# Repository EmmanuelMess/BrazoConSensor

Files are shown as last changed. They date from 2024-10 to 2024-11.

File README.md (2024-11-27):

# Brazo con sensor

Es un brazo con un sensor laser de distancia. Permite tomar y soltar cosas desde una repisa.

## Demostración

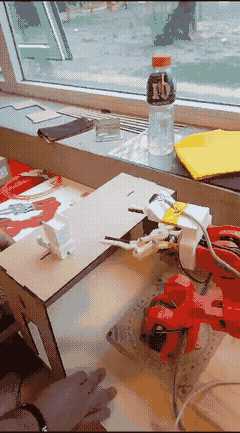
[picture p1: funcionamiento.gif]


## Partes

* 2 Arduino Mega: uno controla el brazo, y otro se comunica con el sensor.
* 2 Fuentes 5V: para los Arduinos.
* 1 Sensor VL6180x: mide la distancia entre el brazo y el objetivo.
* 1 Agarre para sensor: ver "AgarreBrazo.stl"
* 1 Brazo Braccio con agarre gripper
* 1 Repisa: donde el robot toma el objeto

## Instrucciones

1. Imprimir el modelo "AgarreBrazo.stl".
2. Instalar "SensorDetect/SensorDetect.ino" en el arduino del laser (puede requerir instalar dependencias).
3. Instalar "CinematicaInversa/CinematicaInversa.ino" en el arduino Mega del brazo (puede requerir instalar dependencias).
4. Conectar como se explica en el diagrama mas abajo
5. Instalar el agarre al brazo y asegurar que mida correctamente (Ver "Calibrar el sensor")

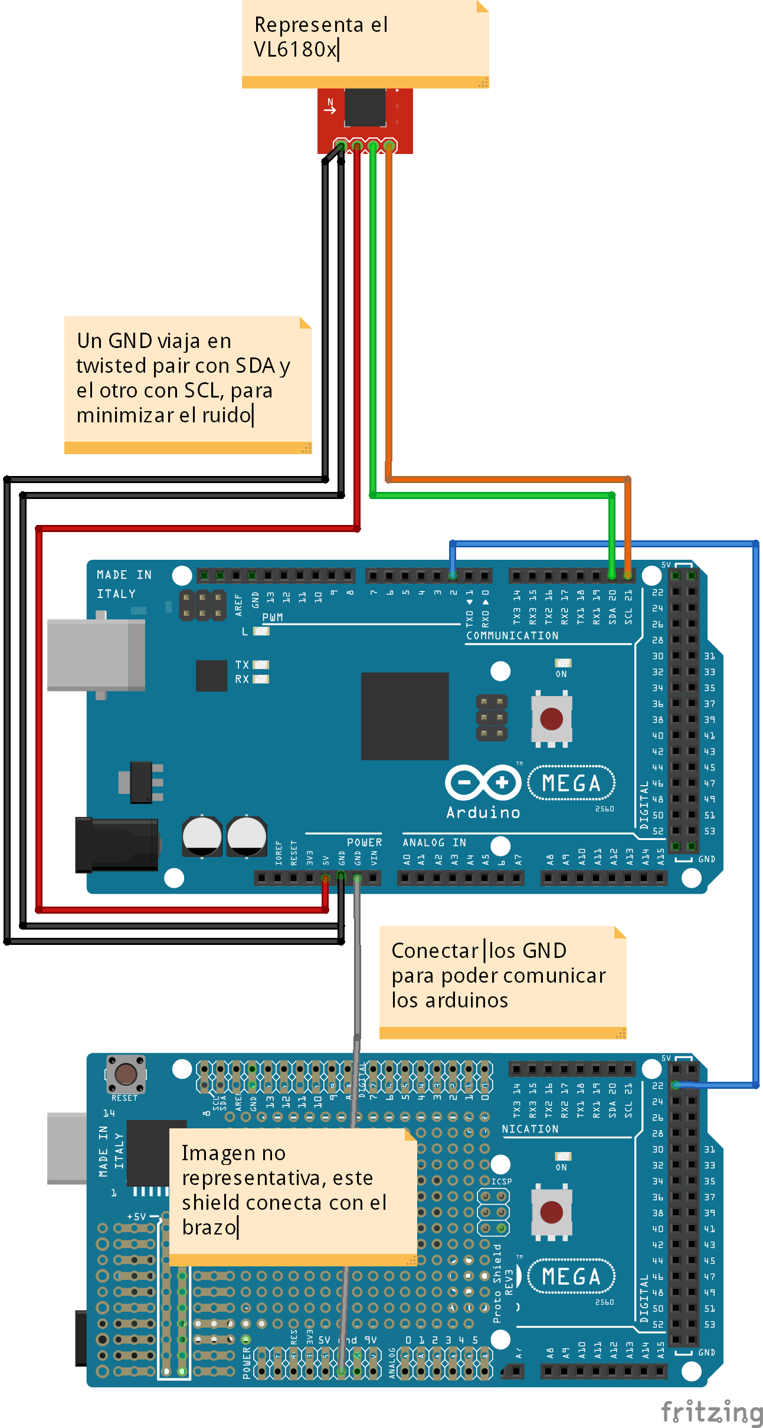
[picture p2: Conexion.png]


### Calibrar el sensor

Alimentar solo el sensor luego de haberlo colocado en el brazo. La salida de consola serial indica 
rangos sensados o errores. Validar que en el rango correcto, el sensor sense correctamente.

## Notas

### Uso de un ultrasonido

El sensor ultrasonido tiene dos problemas: el angulo de deteccion es muy granade y los falsos positivos son muy altos.
El angulo de deteccion del ultrasonido abarca más que el angulo que puede agarrar el brazo, generando choques entre la
mano y el objeto.  Otro problema es que es muy comun una deteccion cuando no hay ningun objeto. Ambos problemas se 
solucionan con un sensor de distancia laser.

### Uso de dos placas

Por cuestiones de mala calidad de los Arduinos, es critico usar dos placas independientes, comunicadas por un pin. Caso contrario,
el movimiento del brazo genera ruido impredecible en la lectura del sensor, generado errores y falsos negativos.

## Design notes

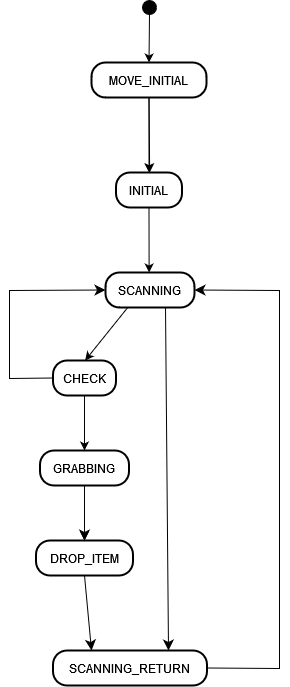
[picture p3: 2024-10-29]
DiagramaDeFlujoBrazo.png

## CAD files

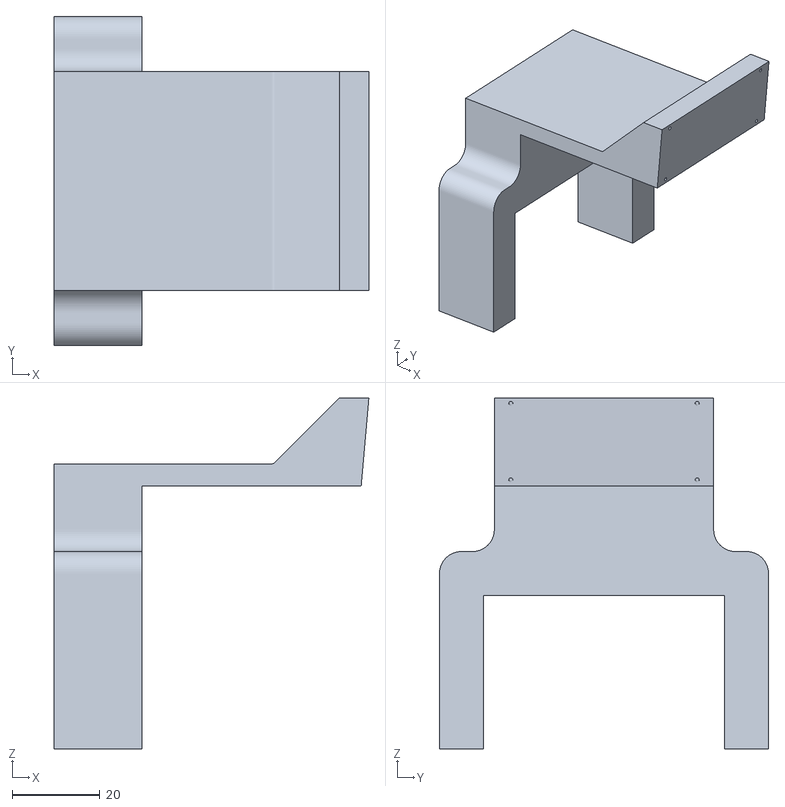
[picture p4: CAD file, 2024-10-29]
AgarreBrazo.stl
71.7 x 75.0 x 80.0

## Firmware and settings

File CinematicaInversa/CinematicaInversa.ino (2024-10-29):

#include <Braccio.h>
#include <Servo.h>

// Include the library InverseK.h
#include <InverseK.h>


const int sensorPin = 22;

Servo base;
Servo shoulder;
Servo elbow;
Servo wrist_rot;
Servo wrist_ver;
Servo gripper;

enum Action {
  INITIAL =  0,
  MOVE_INITIAL,
  GRABBING,
  SCANNING,
  SCANNING_RETURN,
  CHECK,
  DROP_ITEM
};

struct State {
  Action action;
  int x;
  int y;
  int z;
};

State state = { .action = MOVE_INITIAL, .x = -100, .y = 240, .z = 240 };

void printStatePosition() {
    Serial.print("(");
    Serial.print(state.x);
    Serial.print(",");
    Serial.print(state.y);
    Serial.print(",");
    Serial.print(state.z);
    Serial.print(") ");
}

void printAngles(float a0, float a1, float a2, float a3) {
    Serial.print(a2b(a0)); Serial.print(',');
    Serial.print(a2b(a1)); Serial.print(',');
    Serial.print(a2b(a2)); Serial.print(',');
    Serial.println(a2b(a3));
}

void setup() {  
  pinMode(sensorPin, INPUT_PULLUP);

  Braccio.begin();
  
  // Setup the lengths and rotation limits for each link
  Link base, upperarm, forearm, hand;

  base.init(75, b2a(0.0), b2a(180.0));
  upperarm.init(125, b2a(15.0), b2a(165.0));
  forearm.init(125, b2a(0.0), b2a(180.0));
  hand.init(195, b2a(0.0), b2a(180.0));

  // Attach the links to the inverse kinematic model
  InverseK.attach(base, upperarm, forearm, hand);
  
  Serial.begin(9600); 
}  

void loop() {
  if(state.action == MOVE_INITIAL) {
    state.x = -100;
    state.y = -150;
    state.z = 240;
    printStatePosition();

    float a0, a1, a2, a3;
    if(InverseK.solve(state.x, state.y, state.z, a0, a1, a2, a3)) {
      printAngles(a0, a1, a2, a3);
  
      Braccio.ServoMovement(50, a2b(a0), a2b(a1), a2b(a2), a2b(a3), 83,  10);    

      state.action = SCANNING;
      Serial.println("New state.action: SCANNING");
    } else {
      Serial.println("No solution found!");
    }
  } else if(state.action == SCANNING) {
    if(state.y >= 150) {
      state.action = SCANNING_RETURN;
      Serial.println("New state.action: SCANNING_RETURN");

      return;
    }

    state.x = -100;
    state.y += 25;
    state.z = 240;

    printStatePosition();
    
    float a0, a1, a2, a3;
    if(InverseK.solve(state.x, state.y, state.z, a0, a1, a2, a3)) {
      printAngles(a0, a1, a2, a3);
  
      Braccio.ServoMovement(50, a2b(a0), a2b(a1), a2b(a2), a2b(a3), 83,  10);    

      state.action = CHECK;
      Serial.println("New state.action: CHECK");

      delay(500);
    } else {
      Serial.println("No solution found!");

      state.action = MOVE_INITIAL;
      Serial.println("New state.action: MOVE_INITIAL");
    }
  } else if(state.action == SCANNING_RETURN) {
    {
      state.x = -100;
      state.y = 0;
      state.z = 240;
      printStatePosition();
      
      float a0, a1, a2, a3;
      if(InverseK.solve(state.x, state.y, state.z, a0, a1, a2, a3)) {
        printAngles(a0, a1, a2, a3);
    
        Braccio.ServoMovement(50, 146, a2b(a1), a2b(a2), a2b(a3), 83,  10);    
      } else {
        Serial.println("No solution found!");

        state.action = MOVE_INITIAL;
        Serial.println("New state.action: MOVE_INITIAL");
        return;
      }
    }

    {
      state.x = -100;
      state.y = -150;
      state.z = 240;
      printStatePosition();
      
      float a0, a1, a2, a3;
      if(InverseK.solve(state.x, state.y, state.z, a0, a1, a2, a3)) {
        printAngles(a0, a1, a2, a3);
    
        Braccio.ServoMovement(50, a2b(a0), a2b(a1), a2b(a2), a2b(a3), 83,  10);    

        state.action = CHECK;
        Serial.println("New state.action: CHECK");

        delay(500);
      } else {
        Serial.println("No solution found!");

        state.action = MOVE_INITIAL;
        Serial.println("New state.action: MOVE_INITIAL");
        return;
      }
    }
  } else if(state.action == GRABBING) {
    state.x = -200;
    float a0, a1, a2, a3;

    printStatePosition();
    
    if(InverseK.solve(state.x, state.y, state.z, a0, a1, a2, a3)) {
      printAngles(a0, a1, a2, a3);
  
      Braccio.ServoMovement(50, a2b(a0), a2b(a1), a2b(a2), a2b(a3), 83,  10);    
      Braccio.ServoMovement(50, a2b(a0), a2b(a1), a2b(a2), a2b(a3), 83,  73); 
      Braccio.ServoMovement(50, a2b(a0), a2b(a1), a2b(a2), a2b(a3), 83,  10);    

      state.action = SCANNING_RETURN;
      Serial.println("New state.action: SCANNING_RETURN");

      delay(1000);
    } else {
      Serial.println("No solution found!");
    }
  } else if(state.action == CHECK) {   
    if(digitalRead(sensorPin) == HIGH) {
      Serial.println("Distance: OK");

      state.action = GRABBING;
      Serial.println("New state.action: GRABBING");
    } else {
      Serial.println("More than  20cm");
      
      state.action = SCANNING;
      Serial.println("New state.action: SCANNING");
    }

    delay(3000);// This needs to be large because otherwise the cable to the sensor gets a lot of noise
  } else if(state.action == DROP_ITEM) {   
    // TODO
  }
}

// Quick conversion from the Braccio angle system to radians
float b2a(float b){
  return b / 180.0 * PI - HALF_PI;
}

// Quick conversion from radians to the Braccio angle system
float a2b(float a) {
  return (a + HALF_PI) * 180 / PI;
}

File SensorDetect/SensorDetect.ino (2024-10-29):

#include <Wire.h>
#include "Adafruit_VL6180X.h"

const int pinOut = 2;

Adafruit_VL6180X vl = Adafruit_VL6180X();

void setup() {
  pinMode(pinOut, OUTPUT);

  Serial.begin(9600);

  // wait for serial port to open on native usb devices
  while (!Serial) {
    delay(1);
  }
  
  Serial.println("Adafruit VL6180x test!");
  if (! vl.begin()) {
    Serial.println("Failed to find sensor");
    while (1);
  }
  Serial.println("Sensor found!");
}

void loop() {
  float lux = vl.readLux(VL6180X_ALS_GAIN_5);

  Serial.print("Lux: "); Serial.print(lux); Serial.print(" ");
  
  uint8_t range = vl.readRange();
  uint8_t status = vl.readRangeStatus();

  if (status == VL6180X_ERROR_NONE) {
    Serial.print(" Range: "); Serial.print(range); Serial.print(" ");

    if(range > 60) {
      Serial.println("No detection");
      digitalWrite(pinOut, LOW);
    } else {
      Serial.println("Detection");
      digitalWrite(pinOut, HIGH);
    }
  } else {
    digitalWrite(pinOut, LOW);

    // Some error occurred, print it out!
    
    if  ((status >= VL6180X_ERROR_SYSERR_1) && (status <= VL6180X_ERROR_SYSERR_5)) {
      Serial.println("System error");
    }
    else if (status == VL6180X_ERROR_ECEFAIL) {
      Serial.println("ECE failure");
    }
    else if (status == VL6180X_ERROR_NOCONVERGE) {
      Serial.println("No convergence");
    }
    else if (status == VL6180X_ERROR_RANGEIGNORE) {
      Serial.println("Ignoring range");
    }
    else if (status == VL6180X_ERROR_SNR) {
      Serial.println("Signal/Noise error");
    }
    else if (status == VL6180X_ERROR_RAWUFLOW) {
      Serial.println("Raw reading underflow");
    }
    else if (status == VL6180X_ERROR_RAWOFLOW) {
      Serial.println("Raw reading overflow");
    }
    else if (status == VL6180X_ERROR_RANGEUFLOW) {
      Serial.println("Range reading underflow");
    }
    else if (status == VL6180X_ERROR_RANGEOFLOW) {
      Serial.println("Range reading overflow");
    }
  }
  delay(200);
}
